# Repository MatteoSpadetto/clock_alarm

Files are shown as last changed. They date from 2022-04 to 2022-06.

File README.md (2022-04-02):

# alarm_clock
ESP32 clock alarm just for fun with gerber and 3D files

This alarm uses as intrface an IMU so:
1) shaking stop or engange the bell
2) rotation in 3D space change the led matrix RGB colors

With the 3 buttons is possible to set the alarm time.

Time and zone are automatically set via WiFi connection.
7-segment display used to show time and user interface feedbacks.

The box and structure is 3D printed with SLM tech
The matrix led cover was made with a laser cutter on plexiglass

Circuit board PCB was design with KiCad and hand soldered

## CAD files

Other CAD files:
3D_print/Case.ipt
3D_print/CaseBottom.ipt
3D_print/LedMatrix.ipt
3D_print/MinusBtn.ipt
3D_print/OkBtn.ipt
3D_print/OldVersions/Case.0013.ipt
3D_print/OldVersions/CaseBottom.0005.ipt
3D_print/OldVersions/MinusBtn.0003.ipt
3D_print/OldVersions/OkBtn.0003.ipt
3D_print/OldVersions/OkBtn.0004.ipt
3D_print/OldVersions/PlexStick.0002.ipt
3D_print/OldVersions/PlusBtn.0003.ipt
3D_print/OldVersions/StandBtn.0004.ipt
3D_print/OldVersions/StandMatrix.0001.ipt
3D_print/OldVersions/StandMatrix.0006.ipt
3D_print/OldVersions/clock.0014.iam
3D_print/PlexStick.ipt
3D_print/PlusBtn.ipt
3D_print/StandBtn.ipt
3D_print/StandMatrix.ipt
3D_print/clock.iam

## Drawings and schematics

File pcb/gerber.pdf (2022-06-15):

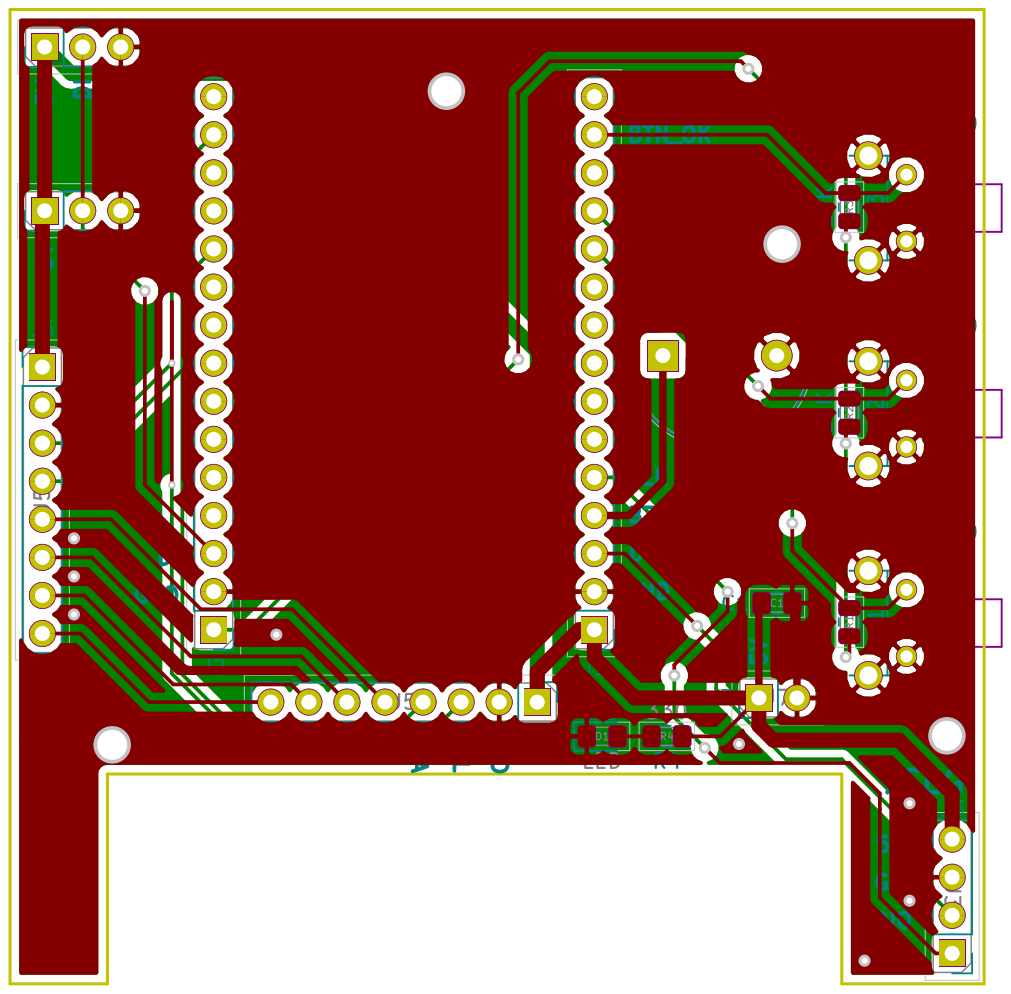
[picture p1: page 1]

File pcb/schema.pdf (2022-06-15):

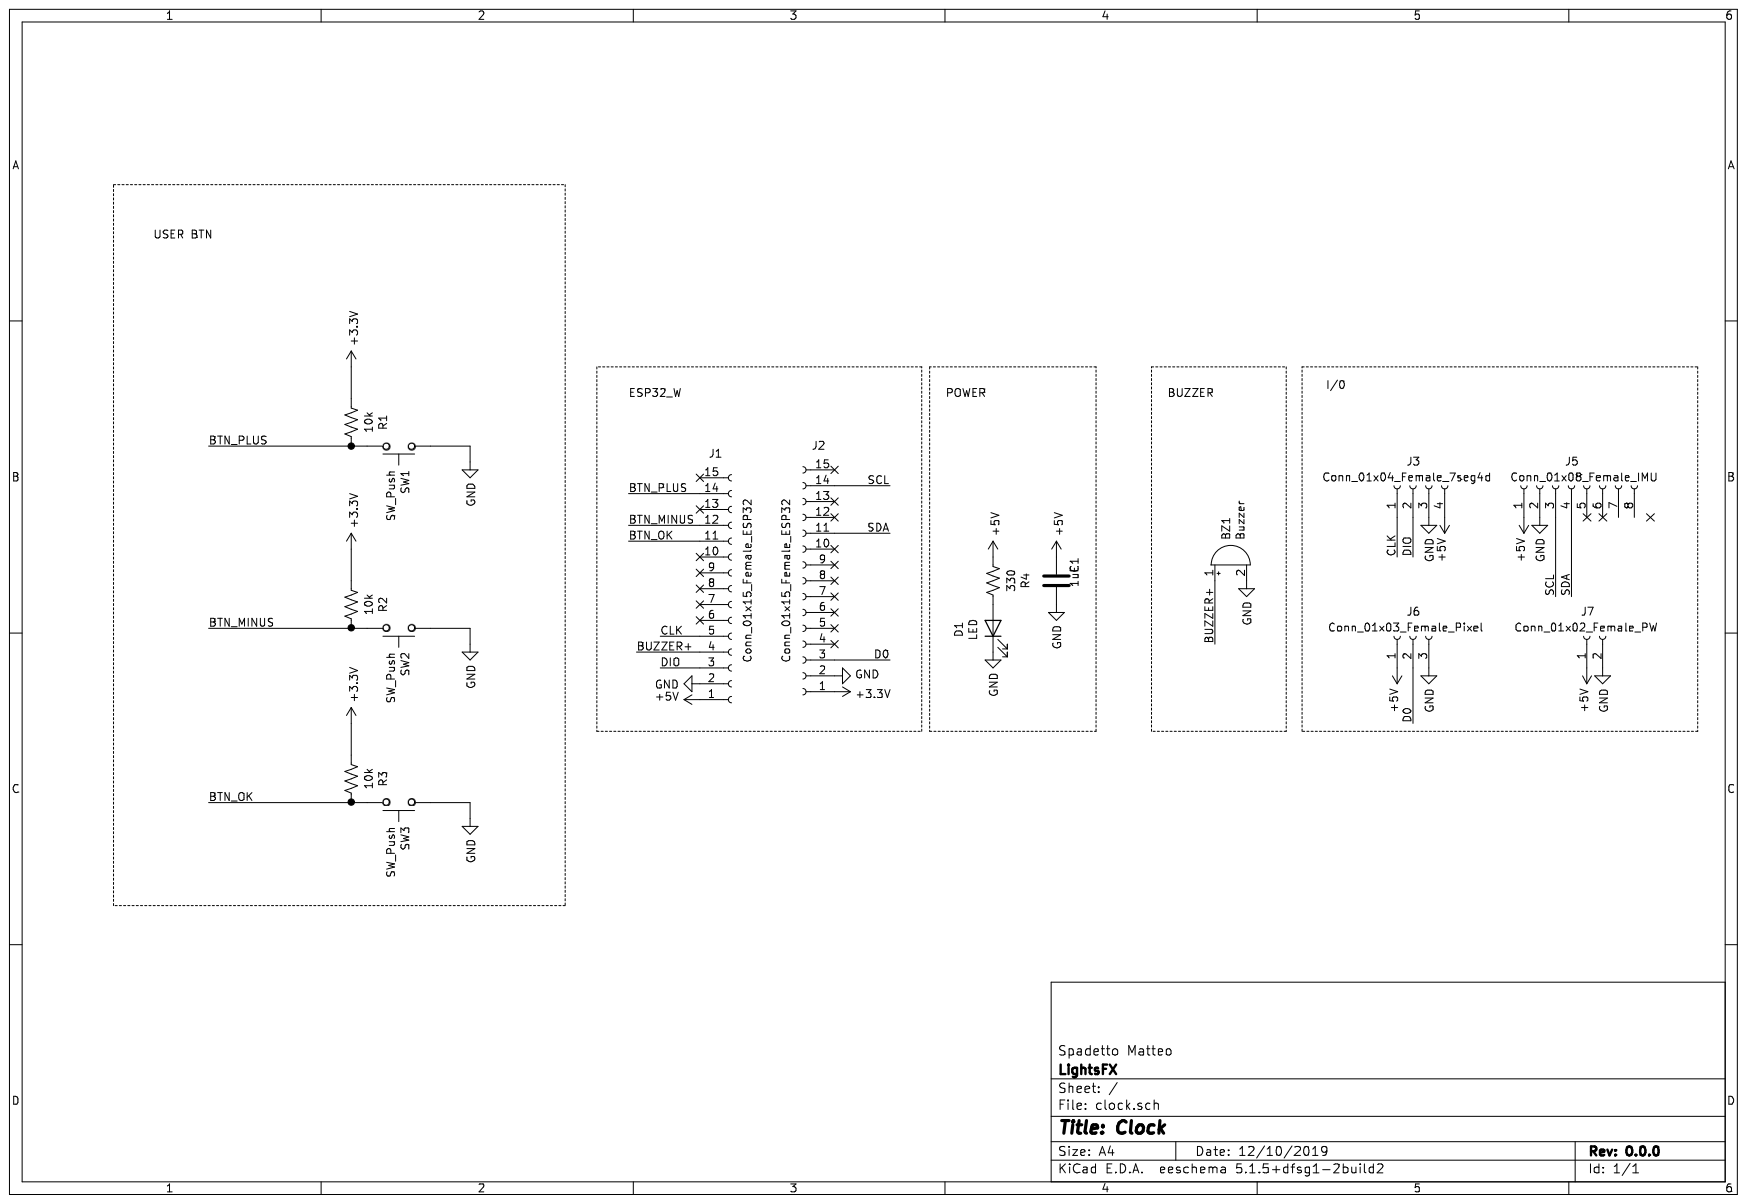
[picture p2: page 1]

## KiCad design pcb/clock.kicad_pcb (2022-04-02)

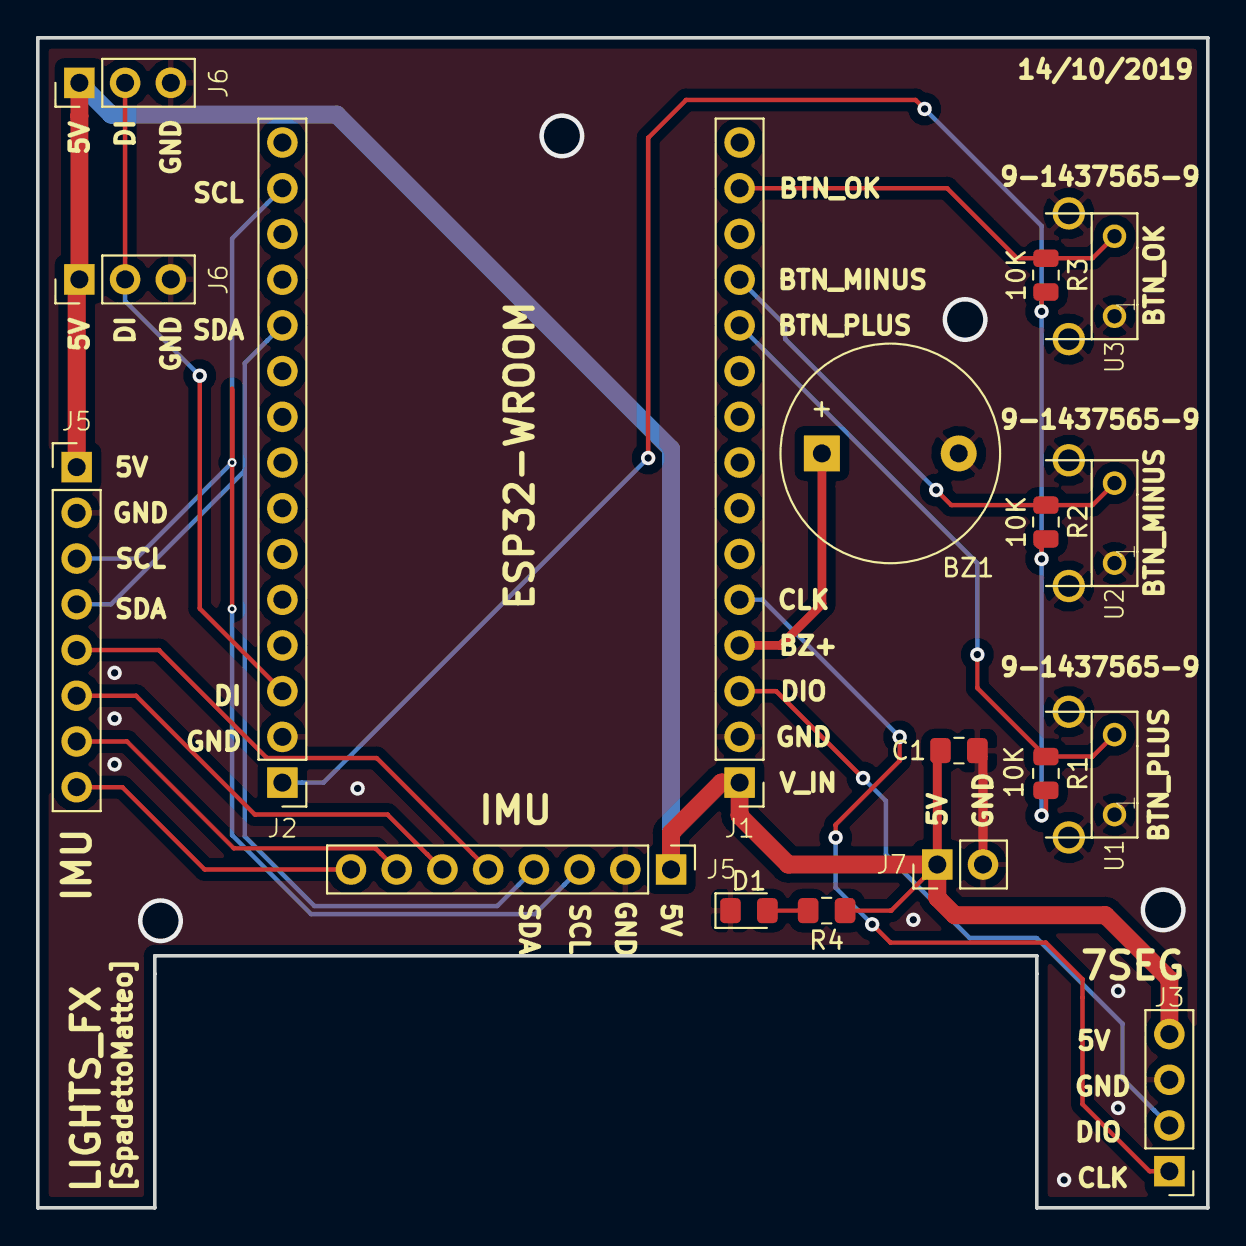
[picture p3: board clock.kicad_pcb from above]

Board: 2 copper layers, 65.0 x 65.0 mm, 18 parts (0 on the bottom side), 17 nets.

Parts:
BZ1: Buzzer; Buzzer_12x9.5RM7.6
C1: 1uF; C_0805_2012Metric_Pad1.15x1.40mm_HandSolder
D1: LED; LED_0805_2012Metric_Pad1.15x1.40mm_HandSolder
J1, J2: Conn_01x15_Female_ESP32; PinHeader_1x15_P2.54mm_Vertical
J3: Conn_01x04_Female_7seg4d; PinHeader_1x04_P2.54mm_Vertical
J5, J5#2: Conn_01x08_Female_IMU; PinHeader_1x08_P2.54mm_Vertical
J6, J6#2: Conn_01x03_Female_Pixel; PinHeader_1x03_P2.54mm_Vertical
J7: Conn_01x02_Female_PW; PinHeader_1x02_P2.54mm_Vertical
R1, R2, R3: 10K; R_0805_2012Metric
R4: 330; R_0805_2012Metric_Pad1.15x1.40mm_HandSolder
U1, U2, U3: 9-1437565-9; FSMRACD

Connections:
+3V3: J2.1, R1.2, R2.2, R3.2
+5V: C1.1, J1.1, J3.4, J5.1, J5#2.1, J6.1, J6#2.1, J7.1, R4.1
/BTN_MINUS: J1.12, R2.1, U2.P$2
/BTN_OK: J1.11, R1.1, U1.P$2
/BTN_PLUS: J1.14, R3.1, U3.P$2
/BUZZER+: BZ1.1, J1.4
/CLK: J1.5, J3.1
/DI: J2.3, J6.2, J6#2.2
/DIO: J1.3, J3.2
/SCL: J2.14, J5.3, J5#2.3
/SDA: J2.11, J5.4, J5#2.4
GND: BZ1.2, C1.2, D1.1, J1.2, J2.2, J3.3, J5.2, J5#2.2, J6.3, J6#2.3, J7.2, U1.GND1, U1.GND2, U1.P$1, U2.GND1, U2.GND2, U2.P$1, U3.GND1, U3.GND2, U3.P$1
unnamed: D1.2, R4.2
unnamed: J5.5, J5#2.5
unnamed: J5.6, J5#2.6
unnamed: J5.7, J5#2.7
unnamed: J5.8, J5#2.8

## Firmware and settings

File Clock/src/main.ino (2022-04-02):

//                             ___          ___                 ___          ___         ___     //
//                            /\__\        /\  \               /\__\        /\__\      /|  |     //
//                 ___       /:/ _/_       \:\  \       ___   /:/ _/_      /:/ _/_    |:|  |     //
//                /\__\     /:/ /\  \       \:\  \     /\__\ /:/ /\  \    /:/ /\__\   |:|  |     //
//  ___     ___  /:/__/    /:/ /::\  \  ___ /::\  \   /:/  //:/ /::\  \  /:/ /:/  / __|:|__|     //
// /\  \   /\__\/::\  \   /:/__\/\:\__\/\  /:/\:\__\ /:/__//:/_/:/\:\__\/:/_/:/  / /::::\__\_____//
// \:\  \ /:/  /\/\:\  \__\:\  \ /:/  /\:\/:/  \/__//::\  \\:\/:/ /:/  /\:\/:/  /  ~~~~\::::/___///
//  \:\  /:/  /  ~~\:\/\__\\:\  /:/  /  \::/__/    /:/\:\  \\::/ /:/  /  \::/__/       |:|~~|    //
//   \:\/:/  /      \::/  / \:\/:/  /    \:\  \    \/__\:\  \\/_/:/  /    \:\  \       |:|  |    //
//    \::/  /       /:/  /   \::/  /      \:\__\        \:\__\ /:/  /      \:\__\      |:|__|    //
//     \/__/        \/__/     \/__/        \/__/         \/__/ \/__/        \/__/      |/__/     //

#include <Arduino.h>
#include <Adafruit_NeoPixel.h>
#include <TM1637Display.h>
#include <Wire.h>
#include <FastLED.h>
#include "WiFi.h"
#include "debug.h"
#include "buzzer.h"
#include "pixel.h"
#include "buttons.h"
#include "timeseg.h"
#include "connection.h"
#include "timeclock.h"
#include "imu.h"

//TODO: on/off alarm

void setup()
{
  //INITIALIZE debug serial port
  Serial.begin(9600);
  //INITIALIZE matrix with "FastLED.h"
  FastLED.addLeds<NEOPIXEL, 15>(leds, NUMPIXELS);
  //INITIALIZE I2C for IMU reading
  IMUI2CInit();
  //INITIALIZE 7-segment display brightness
  display.setBrightness(0x0a);
  //INITIALIZE buzzer pin mode
  ledcSetup(LEDC_CHANNEL_0, LEDC_BASE_FREQ, LEDC_TIMER_8_BIT);
  ledcAttachPin(BUZZERPIN, LEDC_CHANNEL_0);
  //INITIALIZE buttons --> (pin, function, mode)
  pinMode(buttonPlus.PIN, INPUT);
  pinMode(buttonMinus.PIN, INPUT);
  pinMode(buttonOk.PIN, INPUT);
  //INITIALIZE WiFi
  initWiFi();
  //INITIALIZE time reading from ntp-server Turin INRIM
  initTime();
}

void loop()
{
  imuColorSet();
  switch (mode)
  {
  case PIXEL_IMU:
    pixelMode(PIXEL_IMU);
    displaySeg(hours, minutes, TIME);

    break;
  case PIXEL_MOON:
    pixelMode(PIXEL_MOON);
    displaySeg(hours, minutes, TIME);

    break;
  case PIXEL_SUN:
    pixelMode(PIXEL_SUN);
    displaySeg(hours, minutes, TIME);

    break;
  case PIXEL_OFF:
    pixelMode(PIXEL_OFF);
    display.clear();
    break;

  default:
    break;
  }
  onButtonClick();
  playAlarm();
  if (millis() - setAlarmPeriod >= SET_ALARM_TIMEOUT)
  {
    setAlarm = 0;
  }
}

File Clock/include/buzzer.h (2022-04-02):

//                             ___          ___                 ___          ___         ___     //
//                            /\__\        /\  \               /\__\        /\__\      /|  |     //
//                 ___       /:/ _/_       \:\  \       ___   /:/ _/_      /:/ _/_    |:|  |     //
//                /\__\     /:/ /\  \       \:\  \     /\__\ /:/ /\  \    /:/ /\__\   |:|  |     //
//  ___     ___  /:/__/    /:/ /::\  \  ___ /::\  \   /:/  //:/ /::\  \  /:/ /:/  / __|:|__|     //
// /\  \   /\__\/::\  \   /:/__\/\:\__\/\  /:/\:\__\ /:/__//:/_/:/\:\__\/:/_/:/  / /::::\__\_____//
// \:\  \ /:/  /\/\:\  \__\:\  \ /:/  /\:\/:/  \/__//::\  \\:\/:/ /:/  /\:\/:/  /  ~~~~\::::/___///
//  \:\  /:/  /  ~~\:\/\__\\:\  /:/  /  \::/__/    /:/\:\  \\::/ /:/  /  \::/__/       |:|~~|    //
//   \:\/:/  /      \::/  / \:\/:/  /    \:\  \    \/__\:\  \\/_/:/  /    \:\  \       |:|  |    //
//    \::/  /       /:/  /   \::/  /      \:\__\        \:\__\ /:/  /      \:\__\      |:|__|    //
//     \/__/        \/__/     \/__/        \/__/         \/__/ \/__/        \/__/      |/__/     //

#ifndef _BUZZER_H
#define _BUZZER_H

#include <Arduino.h>

#define BUZZERPIN 12

#define LEDC_CHANNEL_0 0    //Using first channel of 16 channels (starting from zero)
#define LEDC_TIMER_8_BIT 8  //Using 13 bit precission for LEDC timer
#define LEDC_BASE_FREQ 2000 //Using 2000 Hz as a LEDC base frequency

#define TONE_MODE 0 //Mode0 = RINGBELL Melody || Mode1 = IMPERIAL MARCH Melody

//Notes for melodies
#define __C 261
#define __D 294
#define __E 329
#define __F 349
#define __G 391
#define __GS 415
#define __A 440
#define __AS 455
#define __B 466
#define __CH 523
#define __CSH 554
#define __DH 587
#define __DSH 622
#define __EH 659
#define __FH 698
#define __FSH 740
#define __GH 784
#define __GSH 830
#define __AH 880

int duration = 0;  //Notes duration
int indexBeat = 0; //Index of the current beat
unsigned long previousMillis = 0;

//Melody for IMPERIAL MARCH
static int melody1[] = {__A, __A, __A, __F, __CH, __A, __F, __CH, __A, 0, __EH, __EH, __EH, __FH, __CH, __GS, __F, __CH, __A, 0};
static int beats1[] = {500, 500, 500, 350, 150, 500, 350, 150, 650, 500, 500, 500, 500, 350, 150, 500, 350, 150, 650, 500};
static int toneNum1 = 19;

static int melody2[] = {__AH, __A, __A, __AH, __GSH, __GH, __FSH, __FH, __FSH, 0, __AS, __DSH, __DH, __CSH, __CH, __B, __CH, 0};
static int beats2[] = {500, 300, 150, 500, 325, 175, 125, 125, 250, 325, 250, 500, 325, 175, 125, 125, 250, 350};
static int toneNum2 = 18;

static int melody3[] = {__F, __GS, __F, __A, __CH, __A, __CH, __EH, 0};
static int beats3[] = {250, 500, 350, 125, 500, 375, 125, 650, 500};
static int toneNum3 = 9;

static int melody4[] = {__F, __GS, __F, __CH, __A, __F, __CH, __A, 0};
static int beats4[] = {250, 500, 375, 125, 500, 375, 125, 650, 650};
static int toneNum4 = 9;

//Melody for RINGBELL
static int melody5[] = {__A, 0};
static int beats5[] = {500, 500};
static int toneNum5 = 2;

void playOneBeat(int note, int duration); //Playing one beat
void playTone(int mode);                  //Playing the full song sections

#endif
